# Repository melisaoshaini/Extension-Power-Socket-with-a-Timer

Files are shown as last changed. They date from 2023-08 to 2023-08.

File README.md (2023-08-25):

# Smart Extension Socket

thyyju

## Introduction
In a world where energy demands are on the rise, and energy costs continue to escalate, the "Smart Extension Socket" project was born out of necessity. This need for energy conservation is particularly pressing in Sri Lanka, where economic crises and shortages of fuel and energy resources compound the issue. Electricity has become an essential part of modern life, powering our daily routines. However, our busy lifestyles sometimes cause us to forget to switch off devices, leading to energy wastage and higher electricity bills. Moreover, supplying power to electronic devices beyond their required time can lead to damage, making it essential to address this problem.

## Project Overview
The "Smart Extension Socket" is designed to tackle these energy conservation challenges. It comprises two main components: the power socket itself and an LCD display with buttons for user interaction. The project followed a systematic development process, starting with simulation in Proteus, microcontroller programming, component selection, and hardware design

## Features
### Power Socket Features
**Timer Functionality:** The core functionality of the power socket is its timer, which allows users to set specific times for devices to turn on and off. This feature reduces energy wastage and ensures devices are powered only when needed.

**Periodical Mode:** Users can automate recurring tasks by activating the periodical mode, providing further convenience.

**User-Friendly Interface:** An LCD display with intuitive buttons enables users to control the extension socket effortlessly. The display shows settings and remaining time details.

**Cost-Effective Components:** The project employs common and cost-effective electronic components available in the local market, making it accessible to a wide range of users.

### Technical Details
**Microcontroller:** The project utilizes the PIC16F628A microcontroller, known for its low power consumption and affordability. Programming is achieved using an Arduino board as a programmer, allowing seamless code integration.

**LCD Display:** A 16x2 LCD display in 4-bit mode serves as the user interface, displaying process status, current options, and remaining time.

**AC-DC Step-Down Module:** An AC-DC step-down module converts the main AC voltage to regulated 5V DC power, ensuring safe and efficient operation.

**Relay Module:** A 5V relay module is used to control power supply to the socket, facilitating the switching of high-current devices with a low-current signal.

**Buzzer:** A buzzer provides an audible signal when a timer operation is complete, notifying users effectively.

## Power Circuit and Design
**Operating Voltage:** The device operates on 230V 50Hz AC voltage, with an AC-DC Step-Down converter used to convert it to 5V DC.

**Current Handling:** The product can handle a maximum current of 13A with appliances and has a maximum device current drain of 500mA.

**Power Consumption:** The extension power socket has a minimal power consumption of 2W, with options to disable the timer and display when not in use.



## PCB and Enclosure Design
**PCB Design:** The PCB design was meticulously created using Altium Designer, ensuring an efficient and compact layout. Power lines were appropriately routed for safety.

**3D Enclosure Design:** The enclosure design was done in SolidWorks, resulting in a 3D enclosure that houses the PCB and components securely. Fasteners were used to connect the top and bottom parts.




## Results and Discussion
**Prototype Testing:** The breadboard prototype underwent rigorous testing, with the LCD display, buttons, and menu system working seamlessly. Minor issues, such as a buzzer problem, were resolved by adding a capacitor.

**Component Integration:** After finalizing the PCB and enclosure design, components were soldered onto the PCB and assembled within the enclosure. Wiring was used to interconnect the components.

**Validation:** The final prototype proved successful, with the LCD display, menu system, and buzzer performing as expected. The project achieved its goals without significant setbacks.

## Conclusion
The "Smart Extension Socket" project represents a comprehensive solution to the pressing issue of energy conservation in an era of increasing energy demands and costs. By combining user-friendly features, cost-effective components, and advanced timer functionality, this project empowers users to manage their energy usage effectively and reduce electricity bills. The meticulous development process, from simulation to hardware design and testing, has resulted in a functional and efficient product that addresses the critical need for energy conservation in our modern world.

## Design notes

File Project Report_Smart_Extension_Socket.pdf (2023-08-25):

Department of Electronic and Telecommunication Engineering

University of Moratuwa

### Extension Power Socket with a Timer

### Group EN-2

Amarasinghe A.M.V.M. | 200027R
Amarasinghe Y.E. | 200029B
Anuradha A.K. | 200041E
Arukgoda A.M.O. | 200051J

This report is submitted as a partial fulfilment of module EN1190

07 October 2022

## Content

## Abstract

As our project we have designed a s an enhanced multiplug which compatible for turn on a device by a specified time past and turning off a device after a specified time. Users can activate the periodical mode of the device to supply the current to the equipment periodically. Also, we developed a model for the user to manually operate the equipment connected to the multiplug. An LCD display is included in the product and that shows all settings and remaining time details to the user. We have designed this product as a solution to the energy waste in Sri Lanka where energy has a high demand. Through this product, user can limit the time that an equipment is connected to power and if needed, they can switch this power socket on off periodically as required.

## 1 Introduction

We live in an era in which energy has a high demand. Therefore, cost of the energy is increasing day by day. In Sri Lanka, this problem is severe because of the current economic crisis and shortage of fuels and energy sources. Most of the things we do in day-to-day life need electricity therefore electricity is essential for living in this era. People are very busy with their work therefore sometimes they forgot to switch off the power supply or device. It causes energy waste. This causes people to pay more than they are supposed to pay for electricity bills. Equally, it is not good to waste energy. Survey results provide evidence for this There is Electrical and Electronic equipment which can be damaged due to supplying power more than the required time. This can be caused sometimes device to be fully damaged or partially damaged.

Our solution for this concern is an extension power socket with a timer. This product is an enhanced multiplug which compatible for turn on a device by a specified time past and turning off a device after a specified time. Users can activate the periodical mode of the device to supply the current to the equipment periodically. Also, we developed a model for the user to manually operate the equipment connected to the multi-plug. An LCD display is included in the product and that shows all settings and remaining time details to the user. Therefore, the user can feel the functioning of the device while giving the inputs and the process of the system. We make our best effort to make a simple UI and great UX for the product so the user can control the device easily by using only four buttons.

This product is powered by a PIC16F628A microcontroller, some common electronic components, and an AC-DC step-down module. All the components we need are available in the local market and are cheap and common. The microcontroller, display, and other electronic components are powered by 5V voltage which is given by 230V AC to 5V DC converter. We use the PIC16F628A microcontroller instead of Atmega328p because PIC Microcontroller is cheaper than Atmega328p and it is capable enough for our purpose. We flash the PIC microcontroller with the .hex file code using an Arduino board as a programmer and use the programmed IC to design the product. The PCB of the device was designed by Altium Designer and the enclosure was designed by Solid works.

This product can turn on and off a device in a time intervals of 99 hours 99 minutes 99 seconds with an accuracy of 1 second. Also, the user can end the timer and turn the device on or off immediately using just one switch. This product beeps when the appliance is turned on and off after the timer counts down to the time set by the user. The power consumption of the device is very low, and the user can disable the timer and display for unnecessary times or save power. A power outage or turning off the timer does not affect the device's available memory, so the user can restart the timer from pause time or reset the timer and create a new countdown time after turning the device back on. There are approximately 2m of wire between the product's wall plug and the appliance's power socket. The product has only one power socket with a fuse that can handle up to 7A current. We use square pins for wall power plugs for safety, and a square and round socket for multi-plug for greater appliance compatibility for timer multiplug design. The overall design is logically complex but physically simple for the user.

## 2 Method

This extension power socket was divided into two main parts, power socket and LCD display with buttons. The project was started by implementing every part of extension power socket using proteus simulation software. We flash the PIC microcontroller with the .hex file code using an Arduino board as a programmer and use the programmed IC to design the product. The PCB of the device was designed by Altium Designer and the enclosure was designed by Solid works.

### 2.1 Components

### 2.1.1 Microcontroller

The microcontroller we used was PIC16F628A microcontroller. PIC16F628A is a CMOS FLASH-based mid-range 8-bit microcontroller that comes with an 18-Pin package, out of which, 16 pins can be used as I/O pins. This microcontroller has 4 MHz of internal oscillator with 128 bytes of EEPROM data memory, packed with a single Capture/Compare/PWM, and a USART module with 2 comparators. Low voltage programming is supported by this microcontroller unit.

The key points we considered to select this microcontroller are its low power consumption and low cost. When we were in initial steps, an Arduino board was used to program the microcontroller. The outer appearance and the pin diagram of PIC16F628A are shown in figure 1 and figure 2 respectively.

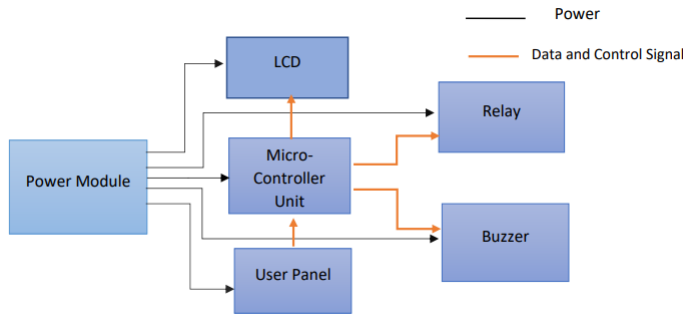
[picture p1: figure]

Figure 1- PIC16F628A package

Figure 2- pin diagram

### 2.1.2 LCD Display

This display was selected due to its compliance to our requirements. The 16x2 LCD display was used in the 4-bit mode. LCD Display acts as the user interface and shows the process status, current option, and time remaining to end the current operation. An image is shown in figure 3.

Figure 3 – 16x2 LCD Display

### 2.1.3 AC-DC step-down module

We used AC-DC step-down module to convert supply AC voltage to DC and reduce the value. Step down module gives regulated 5V DC power to the circuit from the main line. (230V AC to 5V DC) It’s maximum current is 700 mA and maximum power output is 3.5W isolated switching power supply. An image is shown in figure 4.

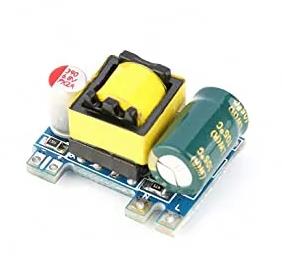
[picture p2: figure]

Figure 4 – AC-DC step down module

### 2.1.4 Relay Module

A 5V relay module is used to Switch off or switch on the power supply to the socket when needed. A 5v relay is an automatic switch (https://www.elprocus.com/what-is-a-centrifugal-switch-and-its-working/) that is commonly used in an automatic control circuit and to control a high-current using a low-current signal. The input voltage of the relay signal ranges from 0 to 5V. An image is shown in figure 5.

Figure 5- 5V Relay module

### 2.1.5 Buzzer

A buzzer is used to give user the signal that the time that has been set is over. Buzzer (https://www.quisure.com/blog/faq/what-is-a-buzzer) is a sounding device that can convert audio signals into sound signals which is powered by DC voltage. An image is shown in figure 6.

Figure 6 – Buzzer

### 2.1.6 Other Components

Table 1 listed the other components we have used except the components listed below.

Component | Value | Quantity
3 core wires | 16/0.20 mm | 2m
Plug top | | 1
Push buttons | | 6
Switch | | 1
18 pin bases | | 1
Resistor | 10 KΩ | 7
Preset resistor | 10 KΩ | 1
2N2222 transistor | | 2
Crystal | 4 MHz | 1
Capacitor | 22pF | 2

Table 1- Other components

### 2.2 Display and Menu

As the first step, the menu and the display were implemented using Proteus simulation. Liquid Crystal library was used for this purpose. Our design has a socket which we can set the time to start and to stop. There are buttons to set the time and to control the operation. We decided to add 5 buttons to operate this extension power socket with a timer.5 buttons are power button, Menu/+ button, select button, enter button and Start/Stop. The purpose of each button is listed below.

### 2.2.1. Power Button

When we press this button, the timer circuit gets powered, and the LCD will display a message saying, “Extension Power Cord with Timer” and then the LCD will display the 1st option of the menu (set on time with the previous set time) automatically.

### 2.2.2. Menu /+ Button

In the display, we can navigate through the three options of the menu (set ON time, set OFF time, Timer Cycle) After selecting a digit place in the time using the select button pressing the menu button will add an increment to the current value.

### 2.2.3. Select Button

Used to select a digit place when setting time, after setting the desired time using the menu button, pressing this button will shift the digit place to the right.

### 2.2.4. Enter Button

After setting the required time in any option (set ON time, set OFF time) or after setting value (1 or 0) to the timer cycle, pressing Enter button will save the changes we made.

### 2.2.5. Start/ Stop Button

After setting the desired set OFF time, set ON time, and timer cycle option, we use this button to start the operation or to terminate a currently ongoing operation instantly.

### 2.3 Power circuit

Operating voltage is 230V 50Hz AC voltage and an AC-DC Step down converter is used to convert 230V AC Voltage to 5V DC Voltage. Maximum Current (With appliance Current) that this product could handle is 13A and maximum device Current drain is 500mA. Power Consumption of this extension power socket is 2W.

### 2.4 PCB Design

The schematic (Appendix 1) of the circuit was drawn first and the PCB (Appendix 2 and 3) was designed accordingly using Altium. The PCB was made small as much as possible. Lines were routed in the top and the bottom layer. 5V power lines were routed at the thickness of 1mm. 230V power lines were routed at the thickness of 2mm.

### 2.5 3D Enclosure

The PCB designed using Altium was exported to Solid works as a 3D step file. Then external parts were imported to the 3D assembly. Next the bottom part of the enclosure and the top part of the enclosure were designed. The top part and the bottom part were connected using fasteners (Appendix 4 and 5).

## 3 Results

The LCD display and the menu worked properly without any failure. The buttons did not have any bouncing effect. The expected scrolling effect of the menu worked properly. The above results were observed using the breadboard prototype. Buzzer worked properly as expected and the final expected result were there without any failures.

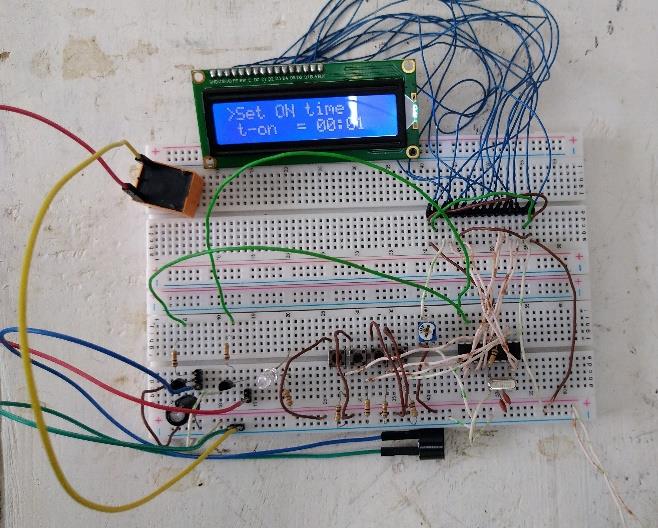
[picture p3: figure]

Figure 7- Breadboard implementation

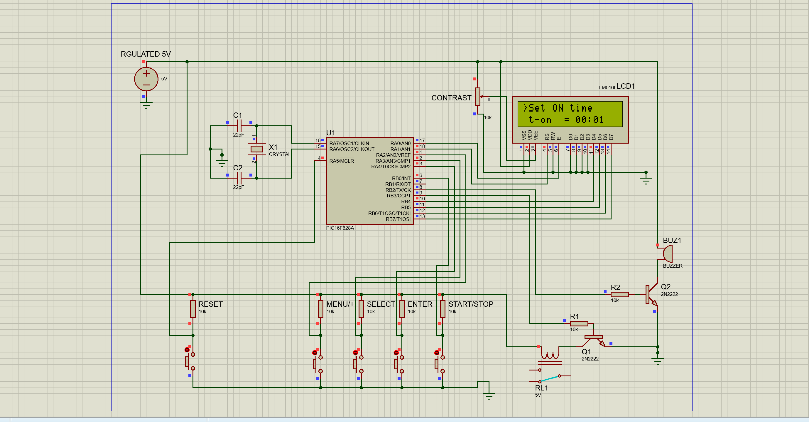
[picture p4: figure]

Figure 8- Proteus Simulation

## 4 Discussion

Each part of the product was separately implemented and then it was combined. Initially PIC16F628A was selected for combining the code. The prototype was successful in the proteus simulation. Next, we implemented the circuit in breadboard prototype. Every component of the circuit worked properly expect buzzer. After connecting a capacitor parallel to the buzzer, buzzer worked properly, and breadboard prototype was complete. At first our plan was to use 6 buttons to control the power socket with display. But after we understood that 5 buttons would be sufficient for the design and changed the buttons by removing reset button. After completing designing the solid works enclosure and PCB design, we printed the enclosure by 3D printing and printed the PCB. Circuit components were successfully soldered to PCB and circuit was placed inside the enclosure. After that we connected each component in the design using wires. LCD display and menu worked properly, and buzzer also worked properly in the prototype. Final expected outcome was there without any failure.

## 4 Project Budget with BOQ

Table 2 – Project Budget

## 5 Acknowledgement

We would like to thank each person who has helped us even in a very small manner in order to achieve good results in this project. We would like to specially thank Dr. Ajith Pasqual. He motivated us to learn the extra subjects required.

## References

https://www.electronics-lab.com/project/pic16f628a-programmable-digital-timer/ (https://www.electronics-lab.com/project/pic16f628a-programmable-digital-timer/)

https://ww1.microchip.com/downloads/en/DeviceDoc/40044G.pdf (https://ww1.microchip.com/downloads/en/DeviceDoc/40044G.pdf)

Component | Price (Rs.)
PIC16F628A | 850
HD44780 LCD | 760
3 core wire (16/0.20mm) 2m | 560
PCB designing | 400
Enclosure 3D printing | 1000
Plug Top | 650
SPMC Power Module | 350
5V-5pin relay | 120
Push Button(x5) | 50
Switch | 10
Buzzer | 60
18 Pin Base | 30
1/4W 10 KΩ Resistor(x7) | 7
Preset Resistor 10KΩ | 10
2N2222 Transistor(x2) | 16
4MHz Crystal | 35
Ceramic Capacitor 22pF(x2) | 4
Total Cost | 4912

## 6 Appendices

### 6.1 Appendix 1 - PCB Schematic

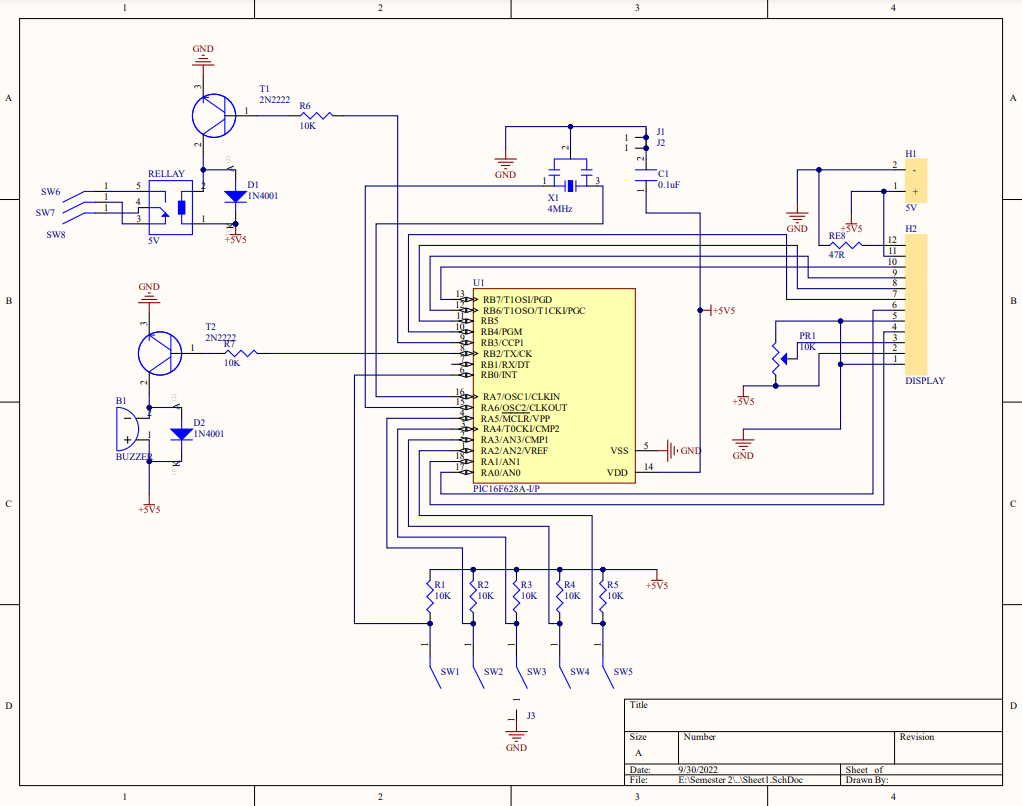
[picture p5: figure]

Appendix 1- PCB Schematic

### 6.2 Appendix 2 - PCB Routing

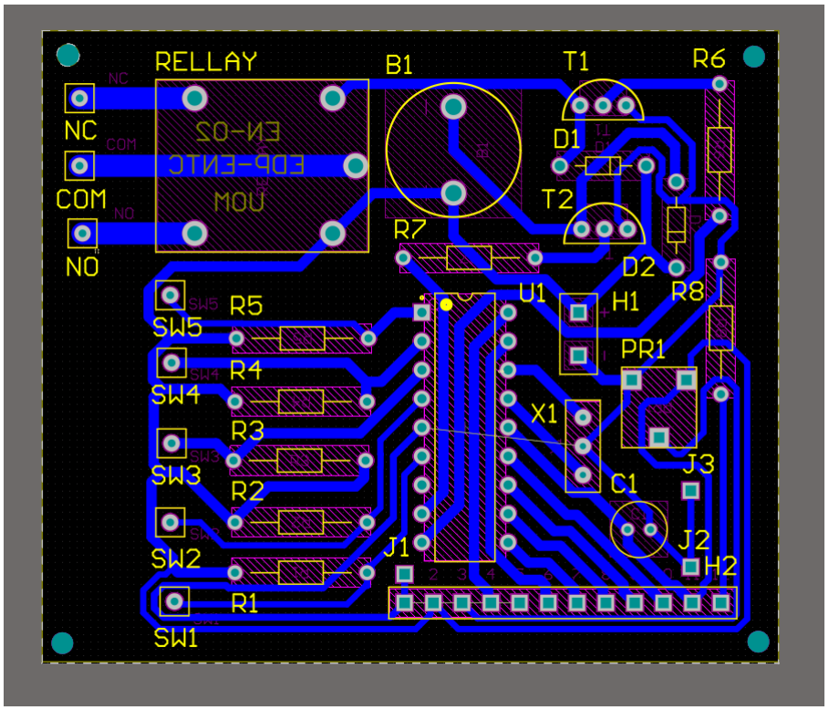
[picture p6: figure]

PCB Routing

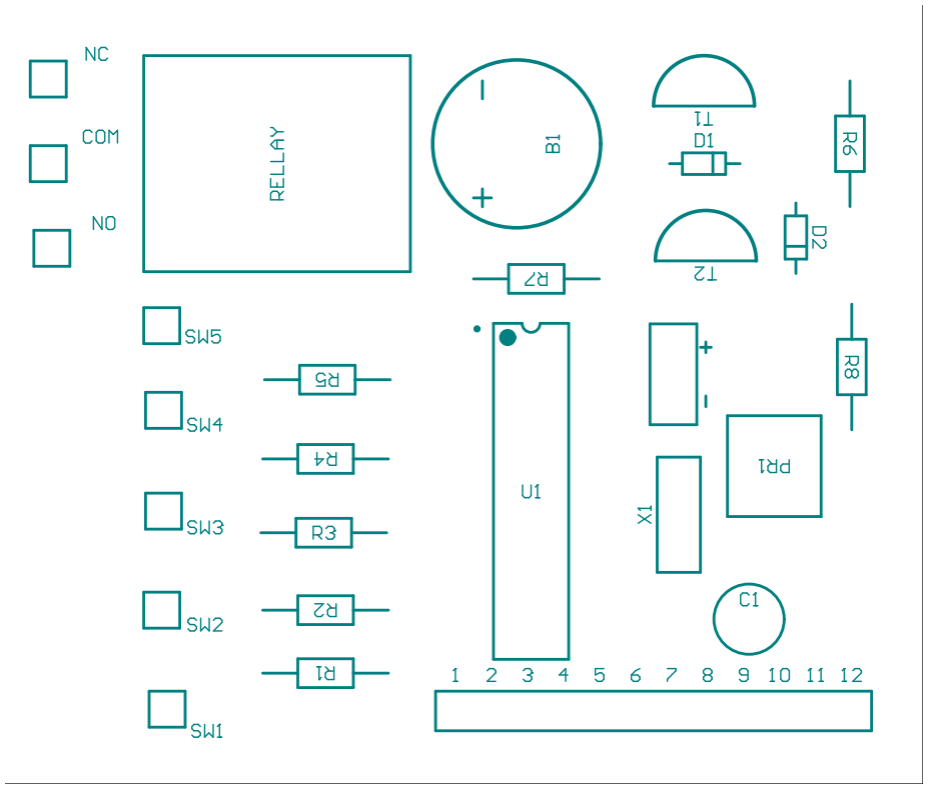
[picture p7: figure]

PCB Assembly Drawing

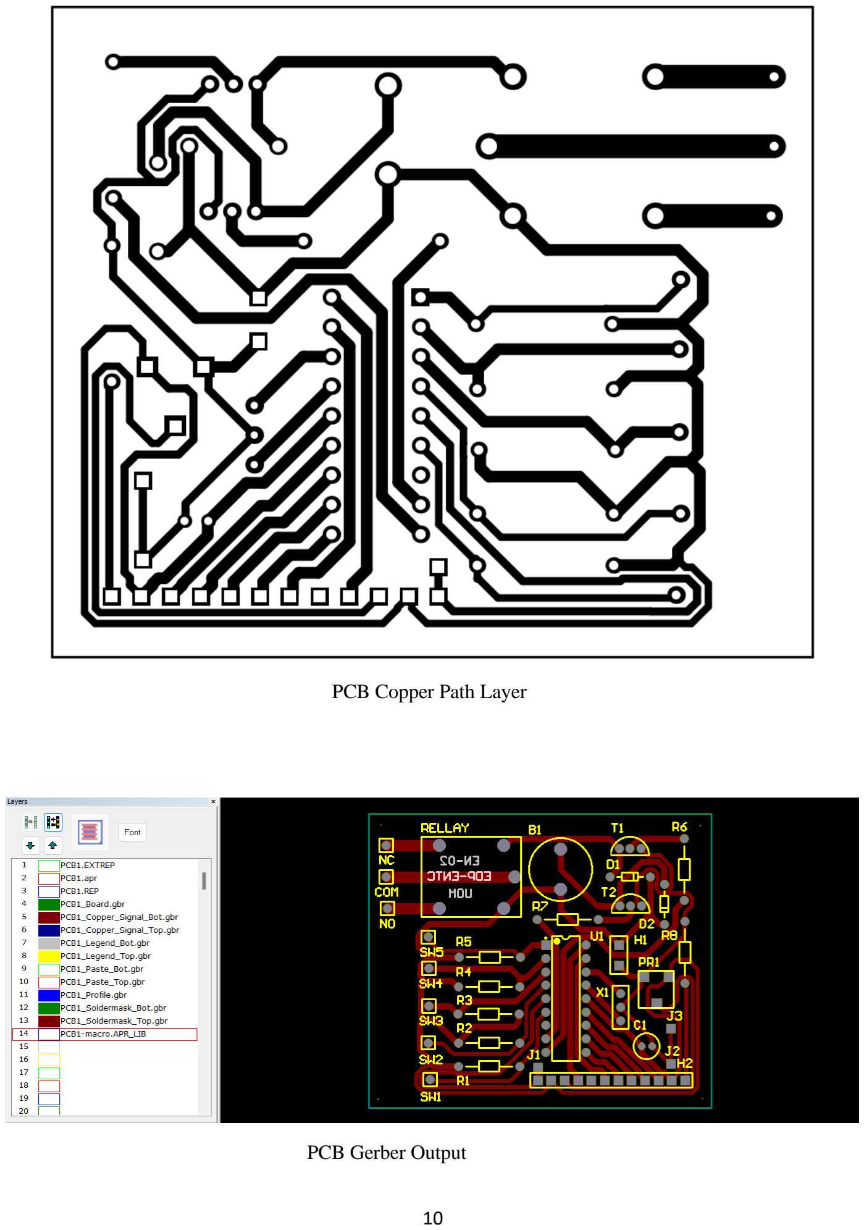
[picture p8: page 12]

PCB Copper Path Layer

PCB Gerber Output

### 6.3 Appendix 3 - PCB 3D View

PCB 3D View Front

PCB 3D View Back

PCB 3D View Angle

### 6.4 Appendix 4 - Enclosure Design

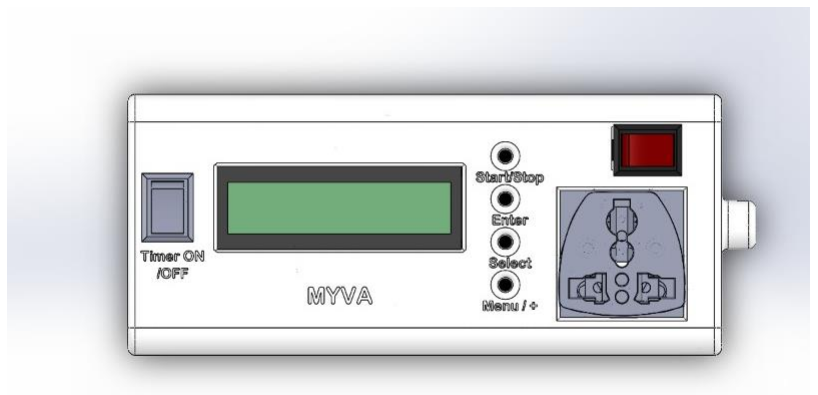
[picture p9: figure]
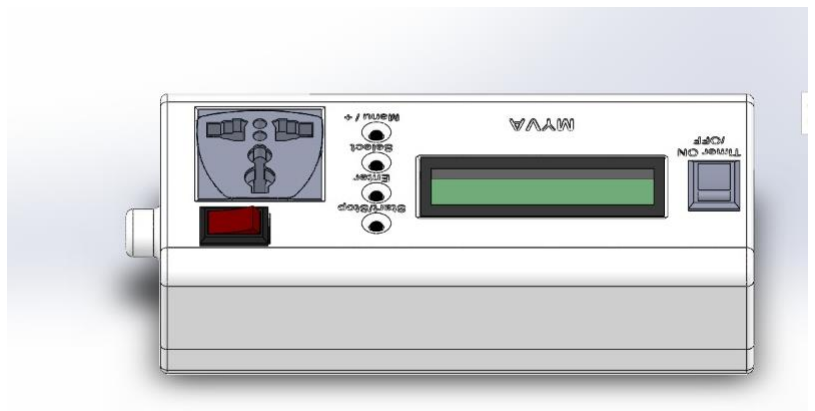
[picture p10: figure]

### 6.5 Appendix 5 - Separated Parts

Consist of 2 part as upper part and lower part.

Upper part

Top view

Bottom view

Front view

Lower part

Top view

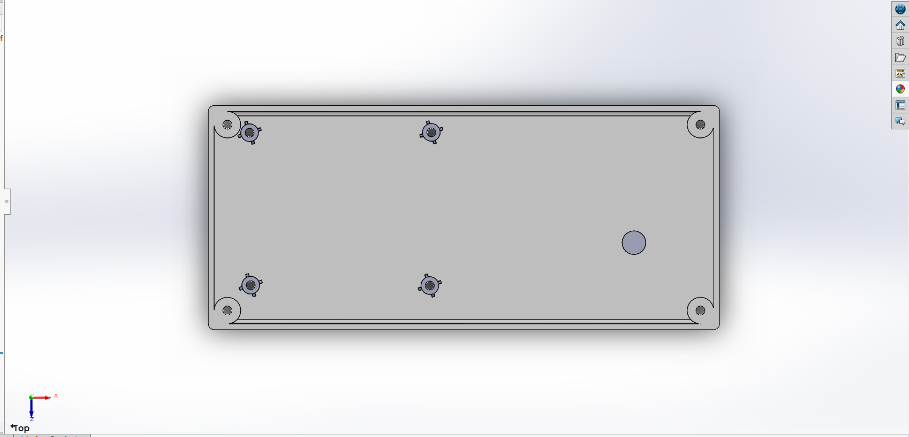
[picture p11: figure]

Bottom view

Front view

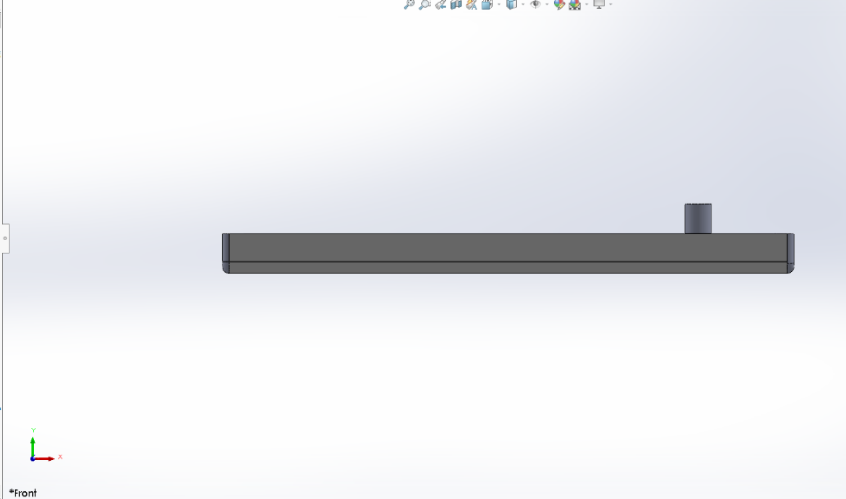
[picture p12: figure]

Assemble

top view

Bottom view

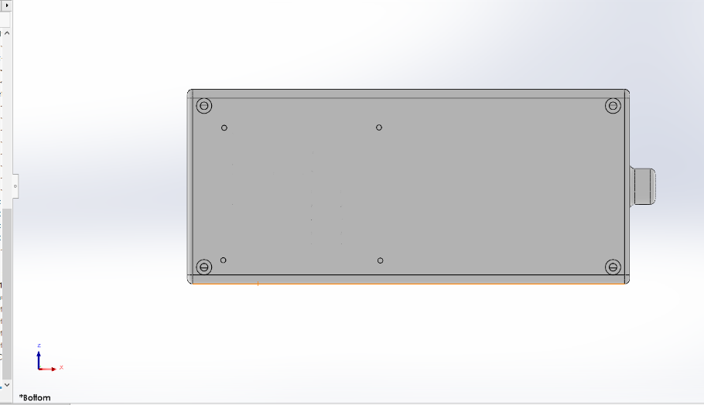
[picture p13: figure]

Front view

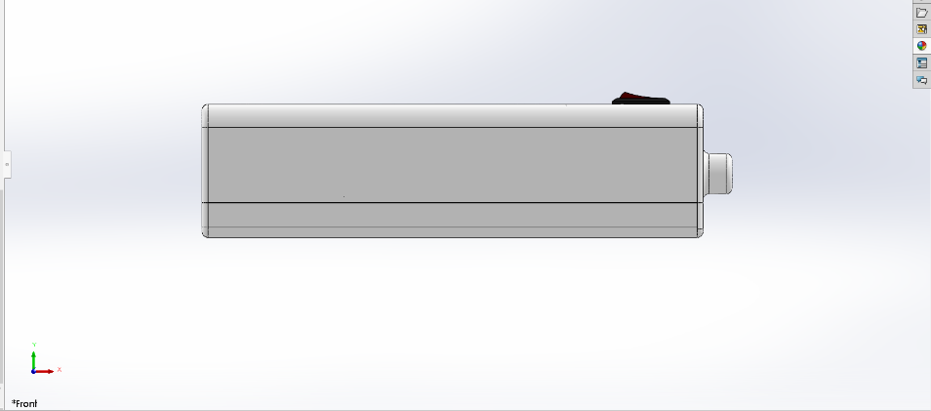
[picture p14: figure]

used 2mm wall thickness after considering the material cost and the strength. As the 1st stage we have only included one socket. we removed the reset button from the user interface as there is no use of a reset button to the user. So, we have used 4 mini push buttons instead of 5 push buttons and place them between the socket and lcd for easy use (can operate by the right hand). we include 2 one-way switches, one on the top of socket which uses to power ON /OFF the socket and other one near the lcd display which uses to ON/OFF the timer.

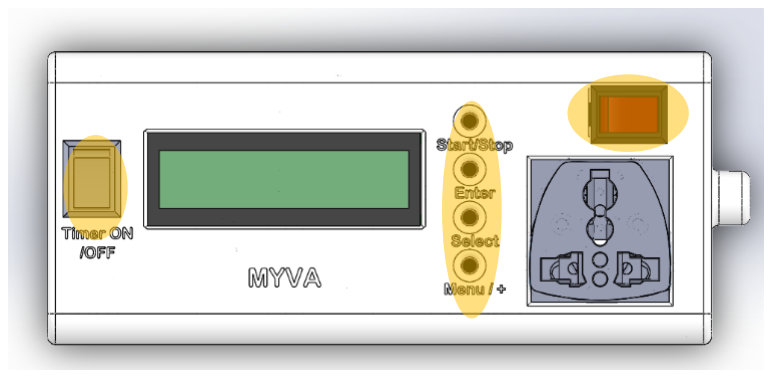
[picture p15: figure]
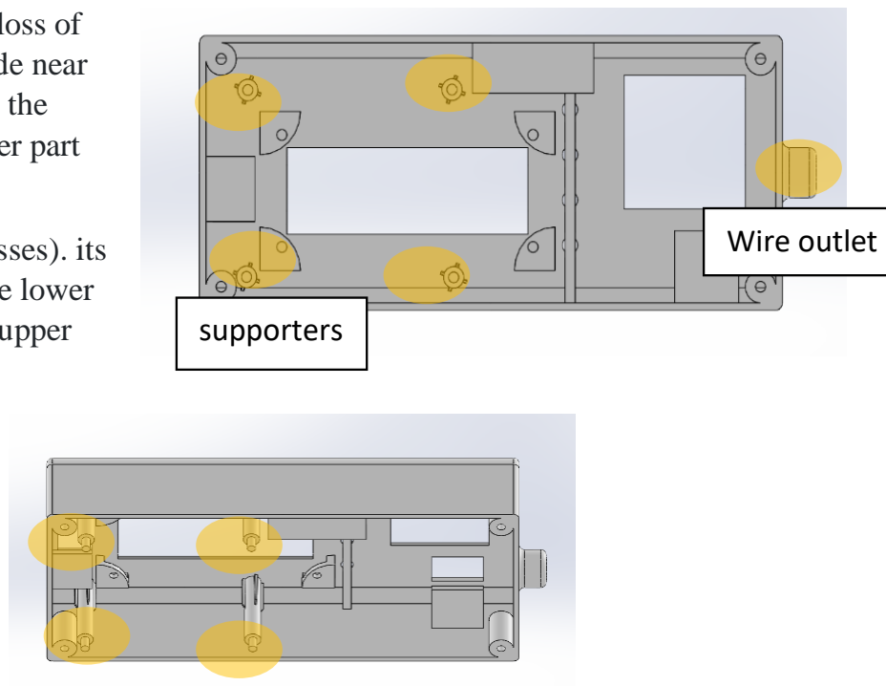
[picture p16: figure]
supporters; Wire outlet

We made an outlet to the 7A wire to prevent the loss of connectivity by unnecessary motions and it is made near the socket to reduce the length of 13A wire inside the product. Lcd display will be connected to the upper part by 4 3mm nuts and bolts using the 4 supporters.

PCB is mounted using mounting bosses (4 pin bosses). its pin side is on the upper part and hole side is on the lower part as we can connect all the components on the upper part and use the lower part as a covering part.

Upper part

Lower part

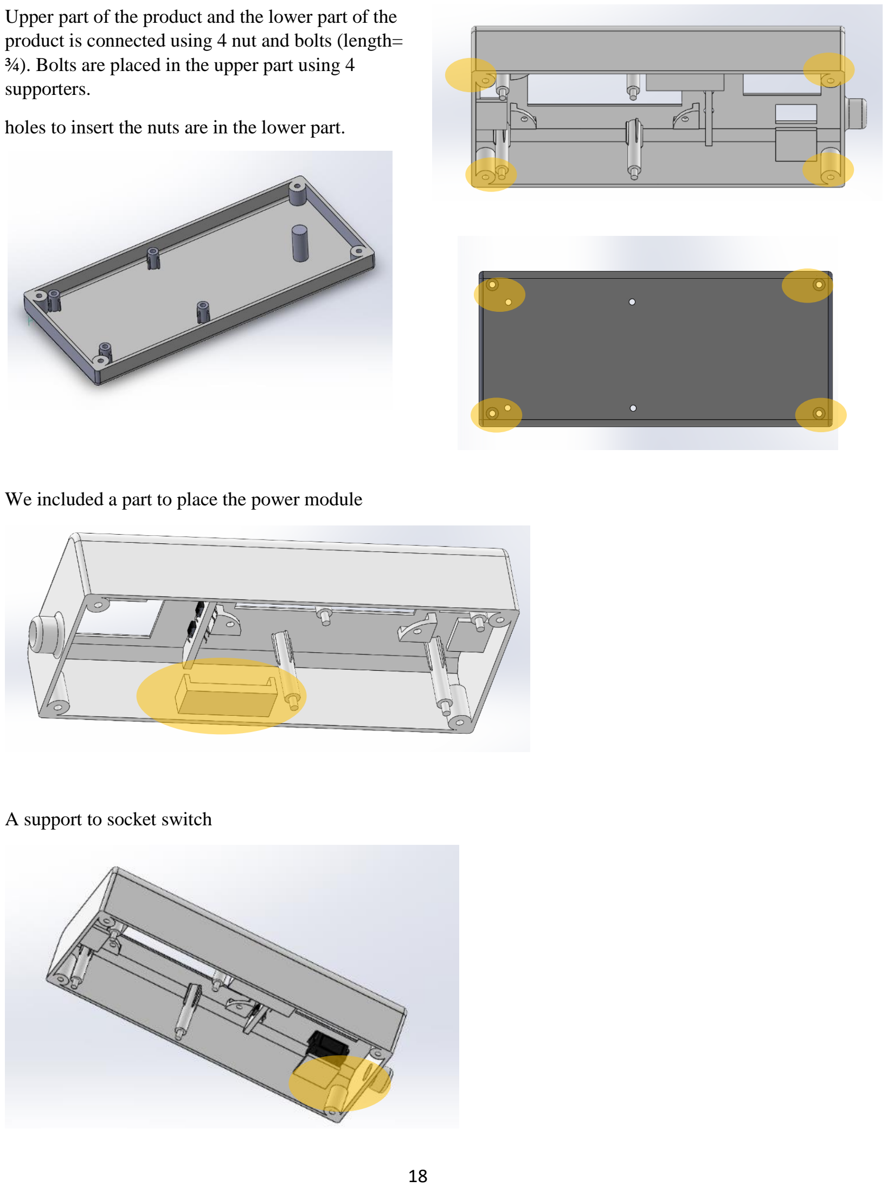
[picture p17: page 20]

Upper part of the product and the lower part of the product is connected using 4 nut and bolts (length= ¾). Bolts are placed in the upper part using 4 supporters.

holes to insert the nuts are in the lower part.

We included a part to place the power module

A support to socket switch

A support to timer switch

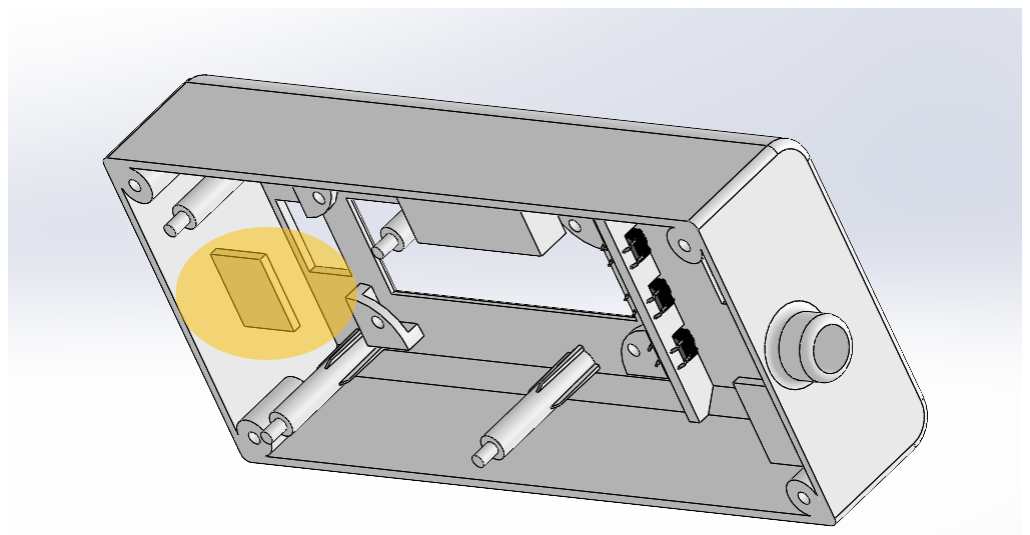
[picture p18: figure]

a part to place 4 buttons

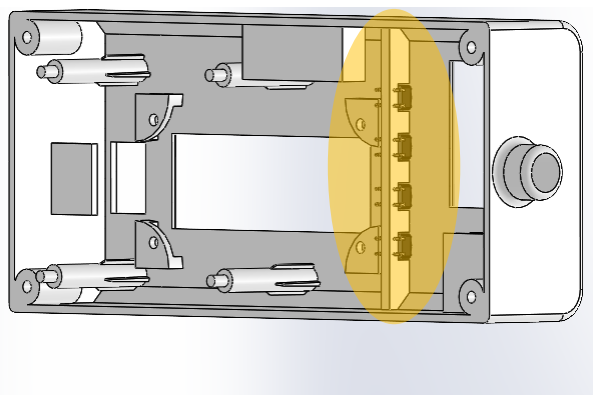
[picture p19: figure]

Supporter to the socket

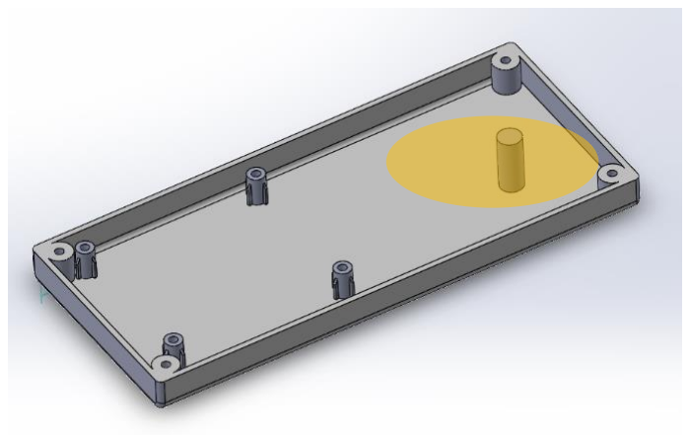
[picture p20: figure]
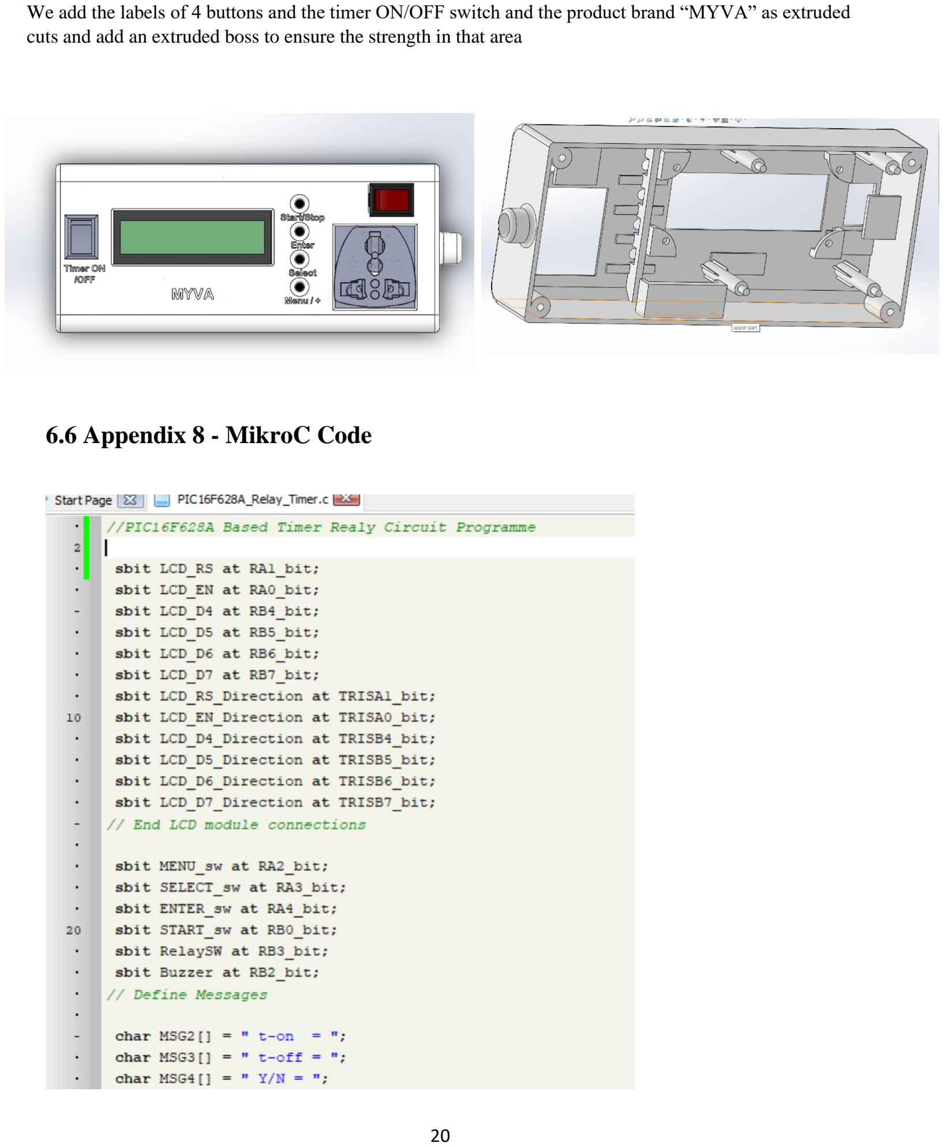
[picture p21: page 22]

We add the labels of 4 buttons and the timer ON/OFF switch and the product brand “MYVA” as extruded cuts and add an extruded boss to ensure the strength in that area

### 6.6 Appendix 8 - MikroC Code

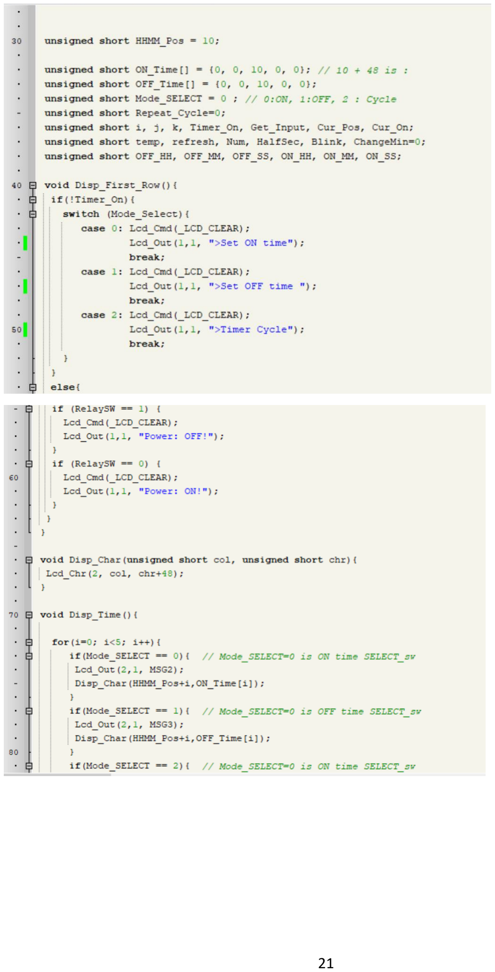
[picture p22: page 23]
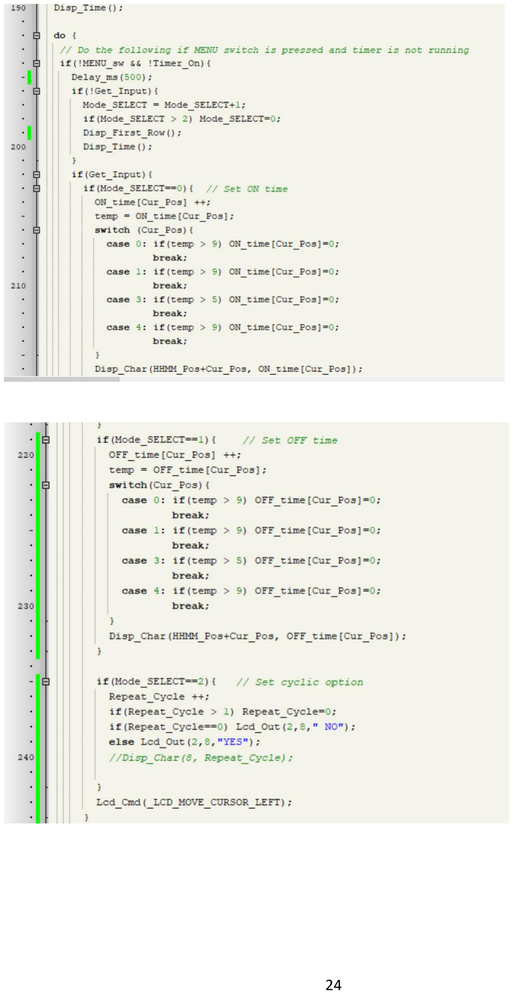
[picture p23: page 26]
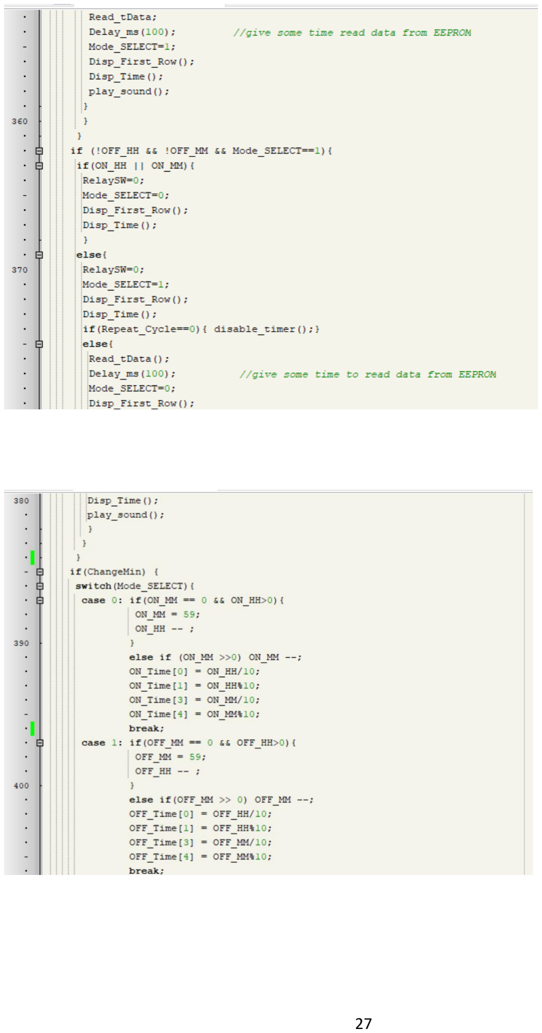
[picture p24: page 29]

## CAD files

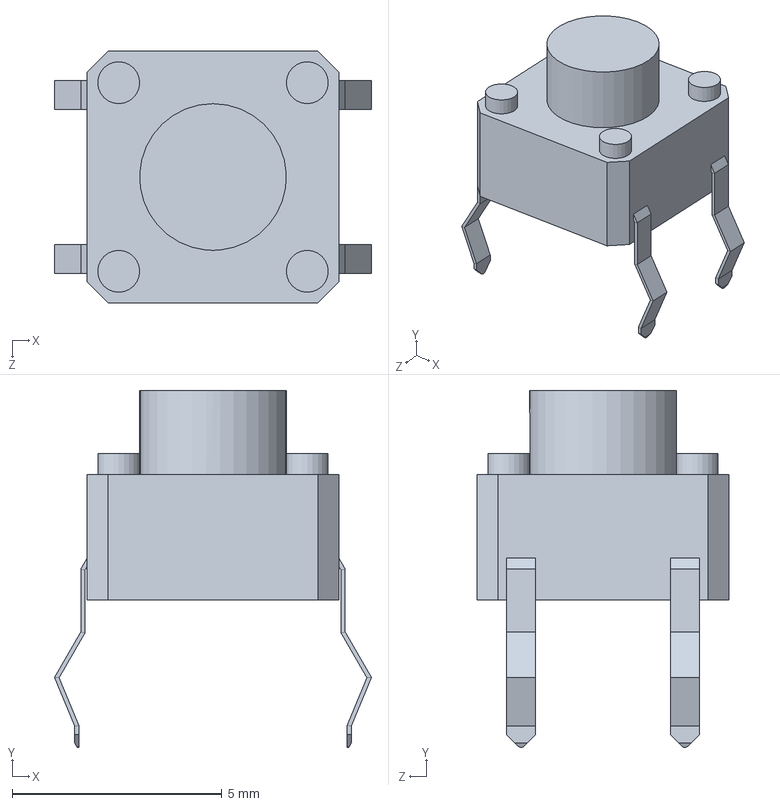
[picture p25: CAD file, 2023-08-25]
Smart_Extension_Socket_Solidworks Enclosure/PushBtn.SLDPRT
7.57 x 8.52 x 6.01 mm

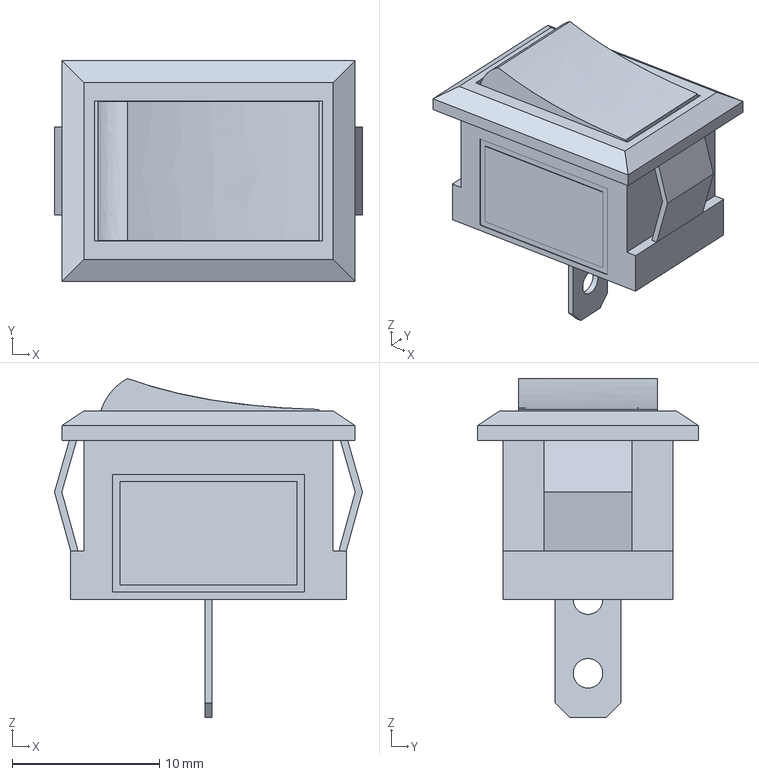
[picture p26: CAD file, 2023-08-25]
Smart_Extension_Socket_Solidworks Enclosure/timer on off.iges
20.9 x 15.0 x 23.0 mm

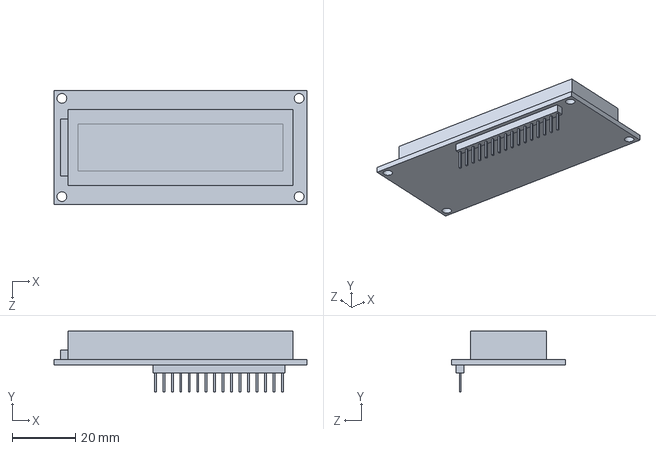
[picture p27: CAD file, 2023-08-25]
Smart_Extension_Socket_Solidworks Enclosure/16x2 LCD Display.SLDPRT
80.1 x 19.3 x 36.1 mm

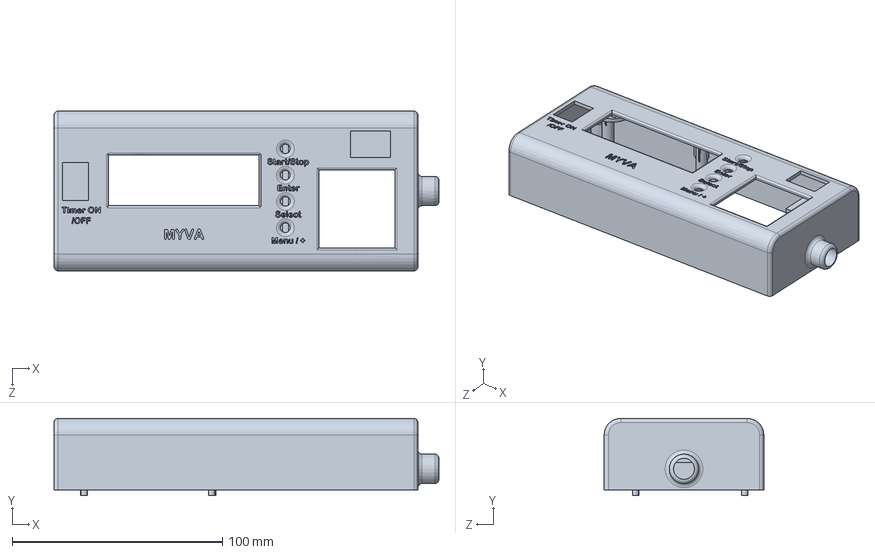
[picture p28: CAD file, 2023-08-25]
Smart_Extension_Socket_Solidworks Enclosure/upper_part_extension.SLDPRT
183.0 x 36.7 x 76.0 mm

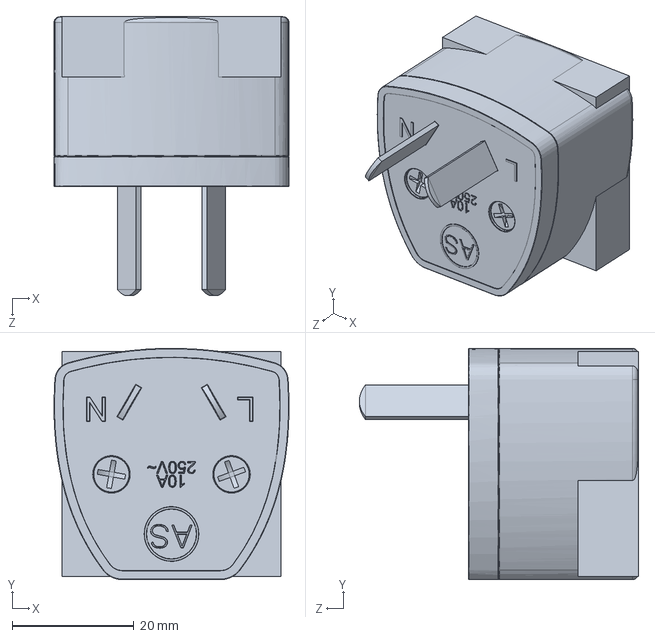
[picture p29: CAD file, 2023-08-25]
Smart_Extension_Socket_Solidworks Enclosure/universal_power_adapter.SLDPRT
38.6 x 38.0 x 45.9 mm

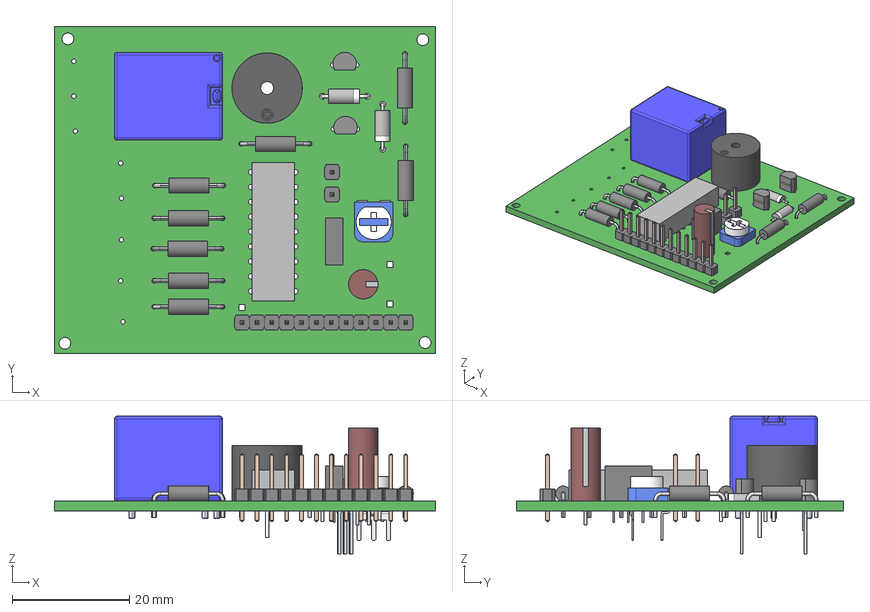
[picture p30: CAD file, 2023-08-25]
Smart_Extension_Socket_Solidworks Enclosure/PCBstepfile.step
65.0 x 55.9 x 23.5 mm
CAP_UEP_5X11_NCH
User_Library-Pot_-_RES_VAR1
CSTLS_8X3_MUR
Extruded
2n2222 x 2
relay5V
YAG_CFR25_YAG x 8
6130xx11121_PIN x 14
Buzzer_5v

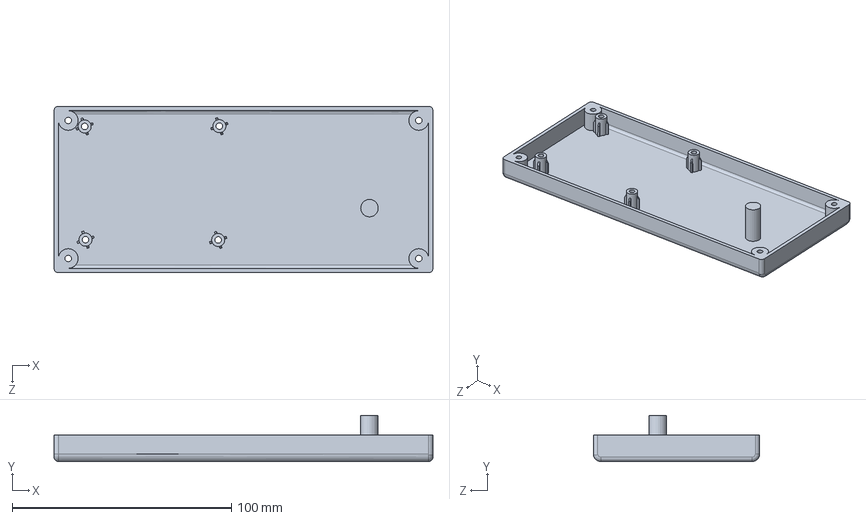
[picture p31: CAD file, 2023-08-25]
Smart_Extension_Socket_Solidworks Enclosure/lower_part_extension.SLDPRT
173.0 x 21.0 x 76.0 mm

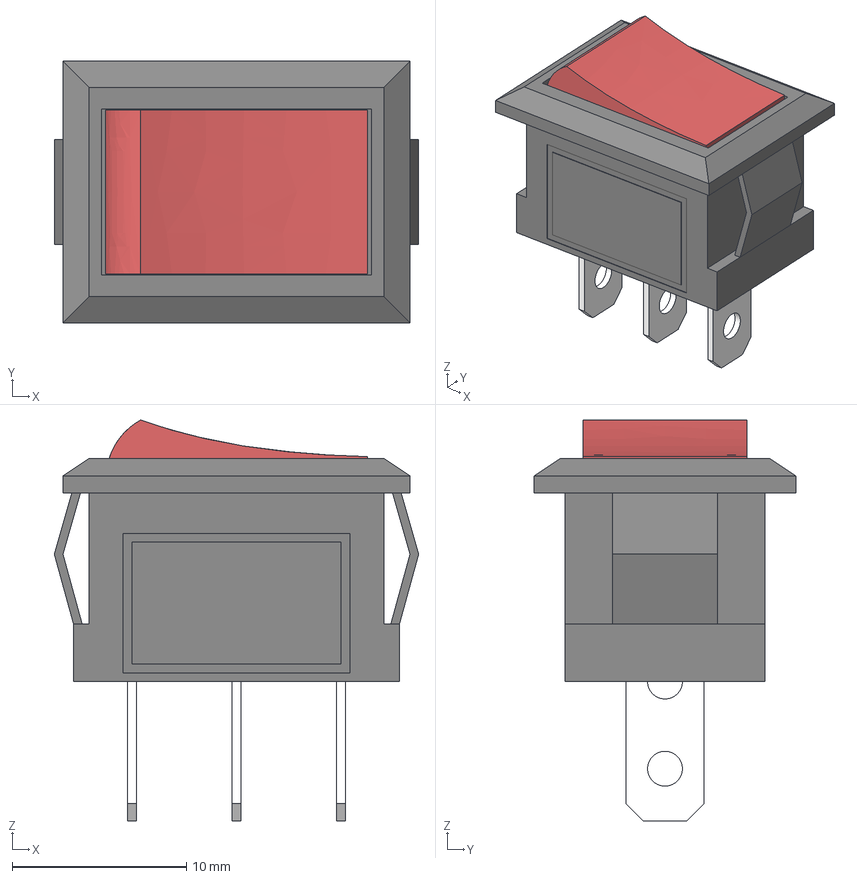
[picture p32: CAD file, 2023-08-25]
Smart_Extension_Socket_Solidworks Enclosure/interruptor_1.step
20.9 x 15.0 x 23.0 mm

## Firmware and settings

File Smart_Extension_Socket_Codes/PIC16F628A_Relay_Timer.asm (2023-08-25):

_Disp_First_Row:

;PIC16F628A_Relay_Timer.c,49 :: 		void Disp_First_Row(){
;PIC16F628A_Relay_Timer.c,50 :: 		if(!Timer_On){
	MOVF       _Timer_On+0, 0
	BTFSS      STATUS+0, 2
	GOTO       L_Disp_First_Row0
;PIC16F628A_Relay_Timer.c,51 :: 		switch (Mode_Select){
	GOTO       L_Disp_First_Row1
;PIC16F628A_Relay_Timer.c,52 :: 		case 0: Lcd_Cmd(_LCD_CLEAR);
L_Disp_First_Row3:
	MOVLW      1
	MOVWF      FARG_Lcd_Cmd_out_char+0
	CALL       _Lcd_Cmd+0
;PIC16F628A_Relay_Timer.c,53 :: 		Lcd_Out(1,1, ">Set OFF time");
	MOVLW      1
	MOVWF      FARG_Lcd_Out_row+0
	MOVLW      1
	MOVWF      FARG_Lcd_Out_column+0
	MOVLW      ?lstr1_PIC16F628A_Relay_Timer+0
	MOVWF      FARG_Lcd_Out_text+0
	CALL       _Lcd_Out+0
;PIC16F628A_Relay_Timer.c,54 :: 		break;
	GOTO       L_Disp_First_Row2
;PIC16F628A_Relay_Timer.c,55 :: 		case 1: Lcd_Cmd(_LCD_CLEAR);
L_Disp_First_Row4:
	MOVLW      1
	MOVWF      FARG_Lcd_Cmd_out_char+0
	CALL       _Lcd_Cmd+0
;PIC16F628A_Relay_Timer.c,56 :: 		Lcd_Out(1,1, ">Set ON time ");
	MOVLW      1
	MOVWF      FARG_Lcd_Out_row+0
	MOVLW      1
	MOVWF      FARG_Lcd_Out_column+0
	MOVLW      ?lstr2_PIC16F628A_Relay_Timer+0
	MOVWF      FARG_Lcd_Out_text+0
	CALL       _Lcd_Out+0
;PIC16F628A_Relay_Timer.c,57 :: 		break;
	GOTO       L_Disp_First_Row2
;PIC16F628A_Relay_Timer.c,58 :: 		case 2: Lcd_Cmd(_LCD_CLEAR);
L_Disp_First_Row5:
	MOVLW      1
	MOVWF      FARG_Lcd_Cmd_out_char+0
	CALL       _Lcd_Cmd+0
;PIC16F628A_Relay_Timer.c,59 :: 		Lcd_Out(1,1, ">Timer Cycle");
	MOVLW      1
	MOVWF      FARG_Lcd_Out_row+0
	MOVLW      1
	MOVWF      FARG_Lcd_Out_column+0
	MOVLW      ?lstr3_PIC16F628A_Relay_Timer+0
	MOVWF      FARG_Lcd_Out_text+0
	CALL       _Lcd_Out+0
;PIC16F628A_Relay_Timer.c,60 :: 		break;
	GOTO       L_Disp_First_Row2
;PIC16F628A_Relay_Timer.c,61 :: 		}
L_Disp_First_Row1:
	MOVF       _Mode_SELECT+0, 0
	XORLW      0
	BTFSC      STATUS+0, 2
	GOTO       L_Disp_First_Row3
	MOVF       _Mode_SELECT+0, 0
	XORLW      1
	BTFSC      STATUS+0, 2
	GOTO       L_Disp_First_Row4
	MOVF       _Mode_SELECT+0, 0
	XORLW      2
	BTFSC      STATUS+0, 2
	GOTO       L_Disp_First_Row5
L_Disp_First_Row2:
;PIC16F628A_Relay_Timer.c,62 :: 		}
	GOTO       L_Disp_First_Row6
L_Disp_First_Row0:
;PIC16F628A_Relay_Timer.c,64 :: 		if (RelaySW == 0) {
	BTFSC      RB3_bit+0, BitPos(RB3_bit+0)
	GOTO       L_Disp_First_Row7
;PIC16F628A_Relay_Timer.c,65 :: 		Lcd_Cmd(_LCD_CLEAR);
	MOVLW      1
	MOVWF      FARG_Lcd_Cmd_out_char+0
	CALL       _Lcd_Cmd+0
;PIC16F628A_Relay_Timer.c,66 :: 		Lcd_Out(1,1, "Device: OFF!");
	MOVLW      1
	MOVWF      FARG_Lcd_Out_row+0
	MOVLW      1
	MOVWF      FARG_Lcd_Out_column+0
	MOVLW      ?lstr4_PIC16F628A_Relay_Timer+0
	MOVWF      FARG_Lcd_Out_text+0
	CALL       _Lcd_Out+0
;PIC16F628A_Relay_Timer.c,67 :: 		}
L_Disp_First_Row7:
;PIC16F628A_Relay_Timer.c,68 :: 		if (RelaySW == 1) {
	BTFSS      RB3_bit+0, BitPos(RB3_bit+0)
	GOTO       L_Disp_First_Row8
;PIC16F628A_Relay_Timer.c,69 :: 		Lcd_Cmd(_LCD_CLEAR);
	MOVLW      1
	MOVWF      FARG_Lcd_Cmd_out_char+0
	CALL       _Lcd_Cmd+0
;PIC16F628A_Relay_Timer.c,70 :: 		Lcd_Out(1,1, "Device: ON!");
	MOVLW      1
	MOVWF      FARG_Lcd_Out_row+0
	MOVLW      1
	MOVWF      FARG_Lcd_Out_column+0
	MOVLW      ?lstr5_PIC16F628A_Relay_Timer+0
	MOVWF      FARG_Lcd_Out_text+0
	CALL       _Lcd_Out+0
;PIC16F628A_Relay_Timer.c,71 :: 		}
L_Disp_First_Row8:
;PIC16F628A_Relay_Timer.c,72 :: 		}
L_Disp_First_Row6:
;PIC16F628A_Relay_Timer.c,73 :: 		}
L_end_Disp_First_Row:
	RETURN
; end of _Disp_First_Row

_Disp_Char:

;PIC16F628A_Relay_Timer.c,75 :: 		void Disp_Char(unsigned short col, unsigned short chr){
;PIC16F628A_Relay_Timer.c,76 :: 		Lcd_Chr(2, col, chr+48);
	MOVLW      2
	MOVWF      FARG_Lcd_Chr_row+0
	MOVF       FARG_Disp_Char_col+0, 0
	MOVWF      FARG_Lcd_Chr_column+0
	MOVLW      48
	ADDWF      FARG_Disp_Char_chr+0, 0
	MOVWF      FARG_Lcd_Chr_out_char+0
	CALL       _Lcd_Chr+0
;PIC16F628A_Relay_Timer.c,77 :: 		}
L_end_Disp_Char:
	RETURN
; end of _Disp_Char

_Disp_Time:

;PIC16F628A_Relay_Timer.c,79 :: 		void Disp_Time(){
;PIC16F628A_Relay_Timer.c,81 :: 		for(i=0; i<5; i++){
	CLRF       _i+0
L_Disp_Time9:
	MOVLW      5
	SUBWF      _i+0, 0
	BTFSC      STATUS+0, 0
	GOTO       L_Disp_Time10
;PIC16F628A_Relay_Timer.c,82 :: 		if(Mode_SELECT == 0){  // Mode_SELECT=0 is OFF time SELECT_sw
	MOVF       _Mode_SELECT+0, 0
	XORLW      0
	BTFSS      STATUS+0, 2
	GOTO       L_Disp_Time12
;PIC16F628A_Relay_Timer.c,83 :: 		Lcd_Out(2,1, MSG2);
	MOVLW      2
	MOVWF      FARG_Lcd_Out_row+0
	MOVLW      1
	MOVWF      FARG_Lcd_Out_column+0
	MOVLW      _MSG2+0
	MOVWF      FARG_Lcd_Out_text+0
	CALL       _Lcd_Out+0
;PIC16F628A_Relay_Timer.c,84 :: 		Disp_Char(HHMM_Pos+i,OFF_Time[i]);
	MOVF       _i+0, 0
	ADDWF      _HHMM_Pos+0, 0
	MOVWF      FARG_Disp_Char_col+0
	MOVF       _i+0, 0
	ADDLW      _OFF_Time+0
	MOVWF      FSR
	MOVF       INDF+0, 0
	MOVWF      FARG_Disp_Char_chr+0
	CALL       _Disp_Char+0
;PIC16F628A_Relay_Timer.c,85 :: 		}
L_Disp_Time12:
;PIC16F628A_Relay_Timer.c,86 :: 		if(Mode_SELECT == 1){  // Mode_SELECT=0 is ON time SELECT_sw
	MOVF       _Mode_SELECT+0, 0
	XORLW      1
	BTFSS      STATUS+0, 2
	GOTO       L_Disp_Time13
;PIC16F628A_Relay_Timer.c,87 :: 		Lcd_Out(2,1, MSG3);
	MOVLW      2
	MOVWF      FARG_Lcd_Out_row+0
	MOVLW      1
	MOVWF      FARG_Lcd_Out_column+0
	MOVLW      _MSG3+0
	MOVWF      FARG_Lcd_Out_text+0
	CALL       _Lcd_Out+0
;PIC16F628A_Relay_Timer.c,88 :: 		Disp_Char(HHMM_Pos+i,ON_Time[i]);
	MOVF       _i+0, 0
	ADDWF      _HHMM_Pos+0, 0
	MOVWF      FARG_Disp_Char_col+0
	MOVF       _i+0, 0
	ADDLW      _ON_Time+0
	MOVWF      FSR
	MOVF       INDF+0, 0
	MOVWF      FARG_Disp_Char_chr+0
	CALL       _Disp_Char+0
;PIC16F628A_Relay_Timer.c,89 :: 		}
L_Disp_Time13:
;PIC16F628A_Relay_Timer.c,90 :: 		if(Mode_SELECT == 2){  // Mode_SELECT=0 is ON time SELECT_sw
	MOVF       _Mode_SELECT+0, 0
	XORLW      2
	BTFSS      STATUS+0, 2
	GOTO       L_Disp_Time14
;PIC16F628A_Relay_Timer.c,91 :: 		Lcd_Out(2,1, MSG4);
	MOVLW      2
	MOVWF      FARG_Lcd_Out_row+0
	MOVLW      1
	MOVWF      FARG_Lcd_Out_column+0
	MOVLW      _MSG4+0
	MOVWF      FARG_Lcd_Out_text+0
	CALL       _Lcd_Out+0
;PIC16F628A_Relay_Timer.c,92 :: 		Disp_Char(8,Repeat_Cycle);
	MOVLW      8
	MOVWF      FARG_Disp_Char_col+0
	MOVF       _Repeat_Cycle+0, 0
	MOVWF      FARG_Disp_Char_chr+0
	CALL       _Disp_Char+0
;PIC16F628A_Relay_Timer.c,93 :: 		Lcd_Out(2,9, "      ");
	MOVLW      2
	MOVWF      FARG_Lcd_Out_row+0
	MOVLW      9
	MOVWF      FARG_Lcd_Out_column+0
	MOVLW      ?lstr6_PIC16F628A_Relay_Timer+0
	MOVWF      FARG_Lcd_Out_text+0
	CALL       _Lcd_Out+0
;PIC16F628A_Relay_Timer.c,95 :: 		break;
	GOTO       L_Disp_Time10
;PIC16F628A_Relay_Timer.c,96 :: 		}
L_Disp_Time14:
;PIC16F628A_Relay_Timer.c,81 :: 		for(i=0; i<5; i++){
	INCF       _i+0, 1
;PIC16F628A_Relay_Timer.c,97 :: 		}
	GOTO       L_Disp_Time9
L_Disp_Time10:
;PIC16F628A_Relay_Timer.c,98 :: 		}
L_end_Disp_Time:
	RETURN
; end of _Disp_Time

_play_sound:

;PIC16F628A_Relay_Timer.c,100 :: 		void play_sound(){
;PIC16F628A_Relay_Timer.c,101 :: 		Buzzer=1;
	BSF        RB2_bit+0, BitPos(RB2_bit+0)
;PIC16F628A_Relay_Timer.c,102 :: 		Delay_ms(500);
	MOVLW      3
	MOVWF      R11+0
	MOVLW      138
	MOVWF      R12+0
	MOVLW      85
	MOVWF      R13+0
L_play_sound15:
	DECFSZ     R13+0, 1
	GOTO       L_play_sound15
	DECFSZ     R12+0, 1
	GOTO       L_play_sound15
	DECFSZ     R11+0, 1
	GOTO       L_play_sound15
	NOP
	NOP
;PIC16F628A_Relay_Timer.c,103 :: 		Buzzer=0;
	BCF        RB2_bit+0, BitPos(RB2_bit+0)
;PIC16F628A_Relay_Timer.c,104 :: 		}
L_end_play_sound:
	RETURN
; end of _play_sound

_Delay_X:

;PIC16F628A_Relay_Timer.c,106 :: 		void Delay_X(){
;PIC16F628A_Relay_Timer.c,107 :: 		Delay_ms(300);
	MOVLW      2
	MOVWF      R11+0
	MOVLW      134
	MOVWF      R12+0
	MOVLW      153
	MOVWF      R13+0
L_Delay_X16:
	DECFSZ     R13+0, 1
	GOTO       L_Delay_X16
	DECFSZ     R12+0, 1
	GOTO       L_Delay_X16
	DECFSZ     R11+0, 1
	GOTO       L_Delay_X16
;PIC16F628A_Relay_Timer.c,108 :: 		}
L_end_Delay_X:
	RETURN
; end of _Delay_X

_cursor_left:

;PIC16F628A_Relay_Timer.c,110 :: 		void cursor_left(){
;PIC16F628A_Relay_Timer.c,111 :: 		for(j=0; j<5; j++){
	CLRF       _j+0
L_cursor_left17:
	MOVLW      5
	SUBWF      _j+0, 0
	BTFSC      STATUS+0, 0
	GOTO       L_cursor_left18
;PIC16F628A_Relay_Timer.c,112 :: 		Lcd_Cmd(_LCD_MOVE_CURSOR_LEFT);
	MOVLW      16
	MOVWF      FARG_Lcd_Cmd_out_char+0
	CALL       _Lcd_Cmd+0
;PIC16F628A_Relay_Timer.c,111 :: 		for(j=0; j<5; j++){
	INCF       _j+0, 1
;PIC16F628A_Relay_Timer.c,113 :: 		}
	GOTO       L_cursor_left17
L_cursor_left18:
;PIC16F628A_Relay_Timer.c,114 :: 		}
L_end_cursor_left:
	RETURN
; end of _cursor_left

_Store_tData:

;PIC16F628A_Relay_Timer.c,116 :: 		void Store_tData(){
;PIC16F628A_Relay_Timer.c,117 :: 		EEPROM_Write(0,OFF_time[0]);
	CLRF       FARG_EEPROM_Write_Address+0
	MOVF       _OFF_Time+0, 0
	MOVWF      FARG_EEPROM_Write_data_+0
	CALL       _EEPROM_Write+0
;PIC16F628A_Relay_Timer.c,118 :: 		EEPROM_Write(1,OFF_time[1]);
	MOVLW      1
	MOVWF      FARG_EEPROM_Write_Address+0
	MOVF       _OFF_Time+1, 0
	MOVWF      FARG_EEPROM_Write_data_+0
	CALL       _EEPROM_Write+0
;PIC16F628A_Relay_Timer.c,119 :: 		EEPROM_Write(2,OFF_time[3]);
	MOVLW      2
	MOVWF      FARG_EEPROM_Write_Address+0
	MOVF       _OFF_Time+3, 0
	MOVWF      FARG_EEPROM_Write_data_+0
	CALL       _EEPROM_Write+0
;PIC16F628A_Relay_Timer.c,120 :: 		EEPROM_Write(3,OFF_time[4]);
	MOVLW      3
	MOVWF      FARG_EEPROM_Write_Address+0
	MOVF       _OFF_Time+4, 0
	MOVWF      FARG_EEPROM_Write_data_+0
	CALL       _EEPROM_Write+0
;PIC16F628A_Relay_Timer.c,121 :: 		EEPROM_Write(4,ON_time[0]);
	MOVLW      4
	MOVWF      FARG_EEPROM_Write_Address+0
	MOVF       _ON_Time+0, 0
	MOVWF      FARG_EEPROM_Write_data_+0
	CALL       _EEPROM_Write+0
;PIC16F628A_Relay_Timer.c,122 :: 		EEPROM_Write(5,ON_time[1]);
	MOVLW      5
	MOVWF      FARG_EEPROM_Write_Address+0
	MOVF       _ON_Time+1, 0
	MOVWF      FARG_EEPROM_Write_data_+0
	CALL       _EEPROM_Write+0
;PIC16F628A_Relay_Timer.c,123 :: 		EEPROM_Write(6,ON_time[3]);
	MOVLW      6
	MOVWF      FARG_EEPROM_Write_Address+0
	MOVF       _ON_Time+3, 0
	MOVWF      FARG_EEPROM_Write_data_+0
	CALL       _EEPROM_Write+0
;PIC16F628A_Relay_Timer.c,124 :: 		EEPROM_Write(7,ON_time[4]);
	MOVLW      7
	MOVWF      FARG_EEPROM_Write_Address+0
	MOVF       _ON_Time+4, 0
	MOVWF      FARG_EEPROM_Write_data_+0
	CALL       _EEPROM_Write+0
;PIC16F628A_Relay_Timer.c,125 :: 		EEPROM_Write(8,1);     // Address 8 stores EEPROM Write flag
	MOVLW      8
	MOVWF      FARG_EEPROM_Write_Address+0
	MOVLW      1
	MOVWF      FARG_EEPROM_Write_data_+0
	CALL       _EEPROM_Write+0
;PIC16F628A_Relay_Timer.c,127 :: 		}
L_end_Store_tData:
	RETURN
; end of _Store_tData

_Read_tData:

;PIC16F628A_Relay_Timer.c,129 :: 		void Read_tData(){
;PIC16F628A_Relay_Timer.c,130 :: 		OFF_time[0]=EEPROM_Read(0);
	CLRF       FARG_EEPROM_Read_Address+0
	CALL       _EEPROM_Read+0
	MOVF       R0+0, 0
	MOVWF      _OFF_Time+0
;PIC16F628A_Relay_Timer.c,131 :: 		OFF_time[1]=EEPROM_Read(1);
	MOVLW      1
	MOVWF      FARG_EEPROM_Read_Address+0
	CALL       _EEPROM_Read+0
	MOVF       R0+0, 0
	MOVWF      _OFF_Time+1
;PIC16F628A_Relay_Timer.c,132 :: 		OFF_time[3]=EEPROM_Read(2);
	MOVLW      2
	MOVWF      FARG_EEPROM_Read_Address+0
	CALL       _EEPROM_Read+0
	MOVF       R0+0, 0
	MOVWF      _OFF_Time+3
;PIC16F628A_Relay_Timer.c,133 :: 		OFF_time[4]=EEPROM_Read(3);
	MOVLW      3
	MOVWF      FARG_EEPROM_Read_Address+0
	CALL       _EEPROM_Read+0
	MOVF       R0+0, 0
	MOVWF      _OFF_Time+4
;PIC16F628A_Relay_Timer.c,134 :: 		ON_time[0]=EEPROM_Read(4);
	MOVLW      4
	MOVWF      FARG_EEPROM_Read_Address+0
	CALL       _EEPROM_Read+0
	MOVF       R0+0, 0
	MOVWF      _ON_Time+0
;PIC16F628A_Relay_Timer.c,135 :: 		ON_time[1]=EEPROM_Read(5);
	MOVLW      5
	MOVWF      FARG_EEPROM_Read_Address+0
	CALL       _EEPROM_Read+0
	MOVF       R0+0, 0
	MOVWF      _ON_Time+1
;PIC16F628A_Relay_Timer.c,136 :: 		ON_time[3]=EEPROM_Read(6);
	MOVLW      6
	MOVWF      FARG_EEPROM_Read_Address+0
	CALL       _EEPROM_Read+0
	MOVF       R0+0, 0
	MOVWF      _ON_Time+3
;PIC16F628A_Relay_Timer.c,137 :: 		ON_time[4]=EEPROM_Read(7);
	MOVLW      7
	MOVWF      FARG_EEPROM_Read_Address+0
	CALL       _EEPROM_Read+0
	MOVF       R0+0, 0
	MOVWF      _ON_Time+4
;PIC16F628A_Relay_Timer.c,138 :: 		}
L_end_Read_tData:
	RETURN
; end of _Read_tData

_disable_timer:

;PIC16F628A_Relay_Timer.c,140 :: 		void disable_timer(){
;PIC16F628A_Relay_Timer.c,141 :: 		INTCON = 0x00;
	CLRF       INTCON+0
;PIC16F628A_Relay_Timer.c,142 :: 		RelaySW = 0;
	BCF        RB3_bit+0, BitPos(RB3_bit+0)
;PIC16F628A_Relay_Timer.c,143 :: 		INTCON.T0IF = 0;
	BCF        INTCON+0, 2
;PIC16F628A_Relay_Timer.c,144 :: 		Timer_On = 0;
	CLRF       _Timer_On+0
;PIC16F628A_Relay_Timer.c,145 :: 		Blink = 0xff;
	MOVLW      255
	MOVWF      _Blink+0
;PIC16F628A_Relay_Timer.c,146 :: 		Mode_SELECT = 0;
	CLRF       _Mode_SELECT+0
;PIC16F628A_Relay_Timer.c,147 :: 		Disp_First_Row();
	CALL       _Disp_First_Row+0
;PIC16F628A_Relay_Timer.c,148 :: 		Read_tData();
	CALL       _Read_tData+0
;PIC16F628A_Relay_Timer.c,149 :: 		Disp_Time();
	CALL       _Disp_Time+0
;PIC16F628A_Relay_Timer.c,150 :: 		play_sound();
	CALL       _play_sound+0
;PIC16F628A_Relay_Timer.c,151 :: 		}
L_end_disable_timer:
	RETURN
; end of _disable_timer

_interrupt:
	MOVWF      R15+0
	SWAPF      STATUS+0, 0
	CLRF       STATUS+0
	MOVWF      ___saveSTATUS+0
	MOVF       PCLATH+0, 0
	MOVWF      ___savePCLATH+0
	CLRF       PCLATH+0

;PIC16F628A_Relay_Timer.c,154 :: 		void interrupt() {
;PIC16F628A_Relay_Timer.c,155 :: 		Num ++;           // Interrupt causes Num to be incremented by 1
	INCF       _Num+0, 1
;PIC16F628A_Relay_Timer.c,156 :: 		if(Num == 9) {
	MOVF       _Num+0, 0
	XORLW      9
	BTFSS      STATUS+0, 2
	GOTO       L_interrupt20
;PIC16F628A_Relay_Timer.c,157 :: 		HalfSec ++;      // Increase sec
	INCF       _HalfSec+0, 1
;PIC16F628A_Relay_Timer.c,158 :: 		Num = 0;
	CLRF       _Num+0
;PIC16F628A_Relay_Timer.c,159 :: 		Blink = ~Blink;
	COMF       _Blink+0, 1
;PIC16F628A_Relay_Timer.c,160 :: 		if (HalfSec == 120){
	MOVF       _HalfSec+0, 0
	XORLW      120
	BTFSS      STATUS+0, 2
	GOTO       L_interrupt21
;PIC16F628A_Relay_Timer.c,161 :: 		HalfSec = 0;
	CLRF       _HalfSec+0
;PIC16F628A_Relay_Timer.c,162 :: 		ChangeMin = 1;
	MOVLW      1
	MOVWF      _ChangeMin+0
;PIC16F628A_Relay_Timer.c,163 :: 		}
L_interrupt21:
;PIC16F628A_Relay_Timer.c,164 :: 		}
L_interrupt20:
;PIC16F628A_Relay_Timer.c,165 :: 		TMR0 = 39;        // TMR0 returns to its initial value
	MOVLW      39
	MOVWF      TMR0+0
;PIC16F628A_Relay_Timer.c,166 :: 		INTCON.T0IF = 0;  // Bit T0IF is cleared so that the interrupt could reoccur
	BCF        INTCON+0, 2
;PIC16F628A_Relay_Timer.c,167 :: 		}
L_end_interrupt:
L__interrupt137:
	MOVF       ___savePCLATH+0, 0
	MOVWF      PCLATH+0
	SWAPF      ___saveSTATUS+0, 0
	MOVWF      STATUS+0
	SWAPF      R15+0, 1
	SWAPF      R15+0, 0
	RETFIE
; end of _interrupt

_main:
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

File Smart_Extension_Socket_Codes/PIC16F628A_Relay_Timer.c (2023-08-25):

/*
 * Project name: Programmable relay switch
 * Description:  Digital timer for a relay switch with cyclic feature
     Author: Rajendra Bhatt, 2016.
     MCU:             PIC16F628A
     Oscillator:      XT, 4.0 MHz
 * Version 4: This version also includes cyclic feature where user can choose cyclic
 option to run the timer in a continuous loop.
*/

// LCD module connections
 sbit LCD_RS at RA1_bit;
 sbit LCD_EN at RA0_bit;
 sbit LCD_D4 at RB4_bit;
 sbit LCD_D5 at RB5_bit;
 sbit LCD_D6 at RB6_bit;
 sbit LCD_D7 at RB7_bit;
 sbit LCD_RS_Direction at TRISA1_bit;
 sbit LCD_EN_Direction at TRISA0_bit;
 sbit LCD_D4_Direction at TRISB4_bit;
 sbit LCD_D5_Direction at TRISB5_bit;
 sbit LCD_D6_Direction at TRISB6_bit;
 sbit LCD_D7_Direction at TRISB7_bit;
// End LCD module connections

 sbit MENU_sw at RA2_bit;
 sbit SELECT_sw at RA3_bit;
 sbit ENTER_sw at RA4_bit;
 sbit START_sw at RB0_bit;
 sbit RelaySW at RB3_bit;
 sbit Buzzer at RB2_bit;
// Define Messages

 char MSG2[] = " t-off = ";
 char MSG3[] = " t-on  = ";
 char MSG4[] = " Y/N = ";


 unsigned short HHMM_Pos = 10;

 unsigned short ON_Time[] = {0, 0, 10, 0, 0}; // 10 + 48 is :
 unsigned short OFF_Time[] = {0, 0, 10, 0, 0};
 unsigned short Mode_SELECT = 0 ; // 0:ON, 1:OFF, 2 : Cycle
 unsigned short Repeat_Cycle=0;
 unsigned short i, j, k, Timer_On, Get_Input, Cur_Pos, Cur_On;
 unsigned short temp, refresh, Num, HalfSec, Blink, ChangeMin=0;
 unsigned short OFF_HH, OFF_MM, OFF_SS, ON_HH, ON_MM, ON_SS;

 void Disp_First_Row(){
  if(!Timer_On){
    switch (Mode_Select){
       case 0: Lcd_Cmd(_LCD_CLEAR);
               Lcd_Out(1,1, ">Set OFF time");
               break;
       case 1: Lcd_Cmd(_LCD_CLEAR);
               Lcd_Out(1,1, ">Set ON time ");
               break;
       case 2: Lcd_Cmd(_LCD_CLEAR);
               Lcd_Out(1,1, ">Timer Cycle");
               break;
    }
  }
  else{
   if (RelaySW == 0) {
     Lcd_Cmd(_LCD_CLEAR);
     Lcd_Out(1,1, "Device: OFF!");
   }
   if (RelaySW == 1) {
     Lcd_Cmd(_LCD_CLEAR);
     Lcd_Out(1,1, "Device: ON!");
   }
  }
 }

 void Disp_Char(unsigned short col, unsigned short chr){
  Lcd_Chr(2, col, chr+48);
 }

 void Disp_Time(){

   for(i=0; i<5; i++){
      if(Mode_SELECT == 0){  // Mode_SELECT=0 is OFF time SELECT_sw
       Lcd_Out(2,1, MSG2);
       Disp_Char(HHMM_Pos+i,OFF_Time[i]);
      }
      if(Mode_SELECT == 1){  // Mode_SELECT=0 is ON time SELECT_sw
       Lcd_Out(2,1, MSG3);
       Disp_Char(HHMM_Pos+i,ON_Time[i]);
      }
      if(Mode_SELECT == 2){  // Mode_SELECT=0 is ON time SELECT_sw
       Lcd_Out(2,1, MSG4);
       Disp_Char(8,Repeat_Cycle);
       Lcd_Out(2,9, "      ");

       break;
      }
   }
 }

 void play_sound(){
  Buzzer=1;
  Delay_ms(500);
  Buzzer=0;
 }

 void Delay_X(){
  Delay_ms(300);
 }

 void cursor_left(){
   for(j=0; j<5; j++){
      Lcd_Cmd(_LCD_MOVE_CURSOR_LEFT);
   }
 }

void Store_tData(){
  EEPROM_Write(0,OFF_time[0]);
  EEPROM_Write(1,OFF_time[1]);
  EEPROM_Write(2,OFF_time[3]);
  EEPROM_Write(3,OFF_time[4]);
  EEPROM_Write(4,ON_time[0]);
  EEPROM_Write(5,ON_time[1]);
  EEPROM_Write(6,ON_time[3]);
  EEPROM_Write(7,ON_time[4]);
  EEPROM_Write(8,1);     // Address 8 stores EEPROM Write flag

}

void Read_tData(){
  OFF_time[0]=EEPROM_Read(0);
  OFF_time[1]=EEPROM_Read(1);
  OFF_time[3]=EEPROM_Read(2);
  OFF_time[4]=EEPROM_Read(3);
  ON_time[0]=EEPROM_Read(4);
  ON_time[1]=EEPROM_Read(5);
  ON_time[3]=EEPROM_Read(6);
  ON_time[4]=EEPROM_Read(7);
}

 void disable_timer(){
  INTCON = 0x00;
  RelaySW = 0;
  INTCON.T0IF = 0;
  Timer_On = 0;
  Blink = 0xff;
  Mode_SELECT = 0;
  Disp_First_Row();
  Read_tData();
  Disp_Time();
  play_sound();
 }


 void interrupt() {
  Num ++;           // Interrupt causes Num to be incremented by 1
  if(Num == 9) {
   HalfSec ++;      // Increase sec
   Num = 0;
   Blink = ~Blink;
   if (HalfSec == 120){
    HalfSec = 0;
    ChangeMin = 1;
   }
  }
  TMR0 = 39;        // TMR0 returns to its initial value
  INTCON.T0IF = 0;  // Bit T0IF is cleared so that the interrupt could reoccur
}



void main() {
  CMCON = 7;           // Disable Comparators
  TRISA = 0b00111100;
  TRISB = 0b00000001;
  PORTB=0;
  PORTA=0;
  RelaySW = 0;
  Timer_On = 0;
  Get_Input = 0;
  Cur_Pos = 0;
  Cur_On = 0;
  refresh = 0;
  Num = 0;
  HalfSec = 0;

  Lcd_Init();                // Initialize LCD
  Lcd_Cmd(_LCD_CLEAR);       // Clear display
  Lcd_Cmd(_LCD_CURSOR_OFF);  // Cursor off
  Lcd_Out(1,1, "PIC-based Relay");
  Lcd_Out(2,1, "Timer V1.0");
  
  i=0;
  while(i<1){
   Delay_X();
   i ++;
  }
  Lcd_Cmd(_LCD_CLEAR);
  Disp_First_Row();
  // Check if there are pre-stored time data in EEPROM
  if(EEPROM_Read(8) == 1){
   Read_tData();
  }
  
  Disp_Time();

  do {
   // Do the following if MENU switch is pressed and timer is not running
   if(!MENU_sw && !Timer_On){
     Delay_X();
     if(!Get_Input){
       Mode_SELECT = Mode_SELECT+1;
       if(Mode_SELECT > 2) Mode_SELECT=0;
       Disp_First_Row();
       Disp_Time();
     }
     if(Get_Input){
       if(Mode_SELECT==0){  // Set OFF time
         OFF_time[Cur_Pos] ++;
         temp = OFF_time[Cur_Pos];
         switch (Cur_Pos){
           case 0: if(temp > 9) OFF_time[Cur_Pos]=0;
                   break;
           case 1: if(temp > 9) OFF_time[Cur_Pos]=0;
                   break;
           case 3: if(temp > 5) OFF_time[Cur_Pos]=0;
                   break;
           case 4: if(temp > 9) OFF_time[Cur_Pos]=0;
                   break;
           case 6: if(temp > 5) OFF_time[Cur_Pos]=0;
                   break;
           case 7: if(temp > 9) OFF_time[Cur_Pos]=0;
                   break;
         }
         Disp_Char(HHMM_Pos+Cur_Pos, OFF_time[Cur_Pos]);

       }
     if(Mode_SELECT==1){    // Set ON time
       ON_time[Cur_Pos] ++;
       temp = ON_time[Cur_Pos];
       switch(Cur_Pos){
        case 0: if(temp > 9) ON_time[Cur_Pos]=0;
               break;
        case 1: if(temp > 9) ON_time[Cur_Pos]=0;
               break;
        case 3: if(temp > 5) ON_time[Cur_Pos]=0;
               break;
        case 4: if(temp > 9) ON_time[Cur_Pos]=0;
               break;
       }
      Disp_Char(HHMM_Pos+Cur_Pos, ON_time[Cur_Pos]);
     }

     if(Mode_SELECT==2){   // Set cyclic option
      Repeat_Cycle ++;
      if(Repeat_Cycle > 1) Repeat_Cycle=0;
      Disp_Char(8, Repeat_Cycle);
     }
     Lcd_Cmd(_LCD_MOVE_CURSOR_LEFT);
    }
   }   // END if(!Menu_sw)
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
